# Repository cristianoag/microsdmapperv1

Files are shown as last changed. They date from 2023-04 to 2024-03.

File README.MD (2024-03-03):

# MSX microSD Mapper Wireless

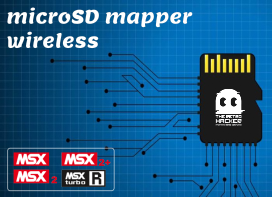
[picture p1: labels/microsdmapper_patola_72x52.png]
MicroSDMapper


The MSX microSD Mapper Wireless is a project aimed at building upon the success of Luciano Sturaro and Fabio Belavenuto's implementation of the well known MSX SD Mapper.

It features a single slot for microSD cards, a ESP8266 (ESP12E) micro-controller to offer wireless access, and simplified board design. 

With microSD cards becoming increasingly affordable and widely available, that seems to be a better option now. Additionally, the original SD Mapper v2 project had some confusion around the switches used to control the megaram/mapper, which were later changed in versions of the firmware to enable and disable the mapper on v2.

The ESP8266 enables network connectivity for the microSD card when it is inserted into the cartridge slot. Through a WebDAV server, it provides a convenient method for accessing and modifying the cartridge storage from any networked PC at any time, without requiring adapters, and eliminating the need for repeatedly removing and reinserting the memory card.

The cartridge also features a small OLED display to present the IP address acquired via DHCP and writes the information on a IP.CFG file on the root of the microSD card so you can create automation based on the address of the microSD Mapper. 

If you need detailed step by step instructions on how to build the cartridge, check the article written on the [The Retro Hacker](https://www.theretrohacker.com) website.

## Hardware Versions

* [microSDmapper v1.0](hardware/microsdmapper_v1.0/) - Initial test board with the basic configuration. (not working)
* [microSDmapper v1.1](hardware/microsdmapper_v1.1/) - Prototype board with the initial circuit, basic wiring for the ESP12E/8266 and a pin header to wire a display to show the MAC, and IP address acquired via DHCP. (not working without bodge wires)
* [microSDmapper v1.2](hardware/microsdmapper_v1.2/) - Prototype board with the validated circuit. Tested with the ESP12E/8266 and the access to the microSD card. (working)

## CPLD

The microSD Mapper is compatible with the standard VHDL code made by Fabio Belavenuto for the well known SD Mapper v2. It uses the Xilinx XC95144XL_TQ100 CPLD.

A copy of the source VHDL code, as well as the synthesized [sdmapper.jed](cpld/sdmapper.jed) file are available on this GitHub repository as a reference.

If you want to synthesize the code by yourself and/or program the CPLD you will need a Xilinx programmer and the Xilinx ISE Webpack.

## ESP8266/ESP12E Firmware

The ESP8266/ESP-12E microcontroller is used in the microSD mapper project to provide convenient access to the microSD card from a WebDav client, such as Windows Explorer. The microcontroller executes a program that implements a basic WebDav server, enabling access to the microSD content and allowing for wireless updates to its content.

Additionally, the microcontroller drives a small 128x32 OLED panel, displaying information on the status of the WebDav server and the IP address obtained by the Wireless interface.

The wireless network can be configured through a small website hosted on the root of the server. Upon the first boot, the ESP8266 activates a SoftAP that listens for HTTP connections made to 192.168.4.1. By accessing this website through a browser, the SSID and password for the wireless connection can be configured. Once saved, this configuration is stored on the ESP8266's EPROM and reused for subsequent connections. Modifications to the wireless configuration parameters can be made at any time by returning to the website.

When the webdav server starts, the code saves a file named IP.CFG on the root of the microSD card. If access to the OLED screen is not available, the IP.CFG file can be used to determine the IP address in use.

The code also monitors the CS signal and attaches itself to the "sdmapper bus". That is to avoid any conflicts with the MSX computer trying to save files at the same time you perform the same via the WebDav server.

## BIOS

The BIOS used on the microSD Mapper is a Nextor ROM that uses the driver created by Fabio Belavenuto and Fabio R. Schmidlin for the original SDMapper. I just made some changes on the assembly code to support the microSD mapper by detecting just one microSD card and also built the ROM using the the current/latest version (2.1.1) of the Nextor base. 

The modified code can be used to build the driver and the MKNEXROM tool can be used to built the Nextor ROM that needs to be flashed to the cartridge.

If you just want to flash a working version of the Nextor ROM to your cartridge, use the [FBL-UPD.COM](software/updater/FBL-UPD.COM) to load the [msdmap.rom](software/driver/msdmap.rom) executing the following command from your MSX-DOS or NEXTOR in a MSX with the microSD Mapper cartridge inserted:

```
FBL-UPD.COM msdmap.rom
```

After executing the command you will get a message that the BIOS was flashed to the cartridge.

If you want to build the driver from the source code, you will need to use [sjasmplus.exe](software/driver/sjasmplus.exe) to build the [driver.bin](software/driver/driver.bin) file and then use the [mknexrom.exe](software/driver/mknexrom.exe) tool to build the [msdmap.rom](software/driver/msdmap.rom) Nextor rom. 

You can do that by executing the commands below from the [driver](software/driver) folder:

```
sjasmplus.exe driver.asm

mknexrom.exe Nextor-2.1.1.base.dat msdmap.rom /d:driver.bin
```

## License 

Open Hardware

This work is licensed under a [Creative Commons Attribution-NonCommercial-ShareAlike 4.0 International License](http://creativecommons.org/licenses/by-nc-sa/4.0/).

* If you remix, transform, or build upon the material, you must distribute your contributions under the same license as the original.
* You may not use the material for commercial purposes.
* You must give appropriate credit, provide a link to the license, and indicate if changes were made. You may do so in any reasonable manner, but not in any way that suggests the licensor endorses you or your use.

**ATTENTION**

This project was made for the retro community and not for commercial purposes. So only retro hardware forums and individual people can build this project.

THE SALE OF ANY PART OF THIS PROJECT WITHOUT EXPRESS AUTHORIZATION IS PROHIBITED!

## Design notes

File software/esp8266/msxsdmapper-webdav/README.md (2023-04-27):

# WebDAV Server for the MSX MicroSD Mapper
This project based on the work done by ardyesp (https://github.com/ardyesp/ESPWebDAV) and synman (https://github.com/synman/ESPWebSvr/tree/sdFat-2.2.0)

The ESP8266/ESP-12E microcontroller is used in the microSD mapper project to provide convenient access to the microSD MSX card from a WebDav client, such as Windows Explorer. The microcontroller executes a program that implements a basic WebDav server, enabling access to the microSD content and allowing for wireless updates to its content.

Additionally, the microcontroller drives a small 128x32 OLED panel (optional), displaying information on the status of the WebDav server and the IP address obtained by the Wireless interface.

The wireless network can be configured through a small website hosted on the root of the server. Upon the first boot, the ESP8266 activates a SoftAP that listens for HTTP connections made to 192.168.4.1. By accessing this website through a browser, the SSID and password for the wireless connection can be configured. Once saved, this configuration is stored on the ESP8266's EPROM and reused for subsequent connections. Modifications to the wireless configuration parameters can be made at any time by returning to the website.

When the webdav server starts, the code saves a file named IP.CFG on the root of the microSD card. If access to the OLED screen is not available, the IP.CFG file can be used to determine the IP address in use.

The code also monitors the CS signal and attaches itself to the "sdmapper bus". That is to avoid any conflicts with the MSX computer trying to save files at the same time you perform the same via the WebDav server.

WiFi WebDAV server using ESP8266 SoC with changes to support the MSX MicroSD Mapper. It maintains the filesystem on an microSD card.

Supports the basic WebDav operations - *PROPFIND*, *GET*, *PUT*, *DELETE*, *MKCOL*, *MOVE* etc.

Once the WebDAV server is running on the ESP8266, a WebDAV client like Windows can access the filesystem on the SD card just like a cloud drive. The drive can also be mounted like a networked drive, and allows copying/pasting/deleting files on SD card remotely.

## Dependencies:
1. Adafruit GFX Library @ 1.11.5
2. Adafruit SSD1306 @ 2.5.7
3. SdFat @ 2.2.2

## Build And Deploy:

The card should be formatted for Fat16. The code also supports FAT32, but it works better with MSX if the card is formatted with FAT16.

This project is fully compatible with PlatformIO. Additionally, OTA is fully supported for subsequent flashes of the sketch over Wi-Fi.

Be sure to reset your adapter using its reset button after uploading a new firmware over USB.  The ESP8266 series modules will not properly reset / reboot
after a USB flash if not reset via their reset button first.  This limitation does not apply to OTA updates.

## Initial Setup
After booting the MSX with the microSD cartridge, wait approximately 60 seconds so the SoftAP gets activated. Once it indicates the WebDav server is running, connect to its Wi-Fi AP (MSXSDMAPPER).

Open up a browser and visit http://192.168.4.1

Fill in the hostname, ssid, and password fields with values that meet your needs and click the `Save` button.  Press the back button in your 
browser, refresh the page, and verify the values you entered meet your requirements.  Click the `Reboot` button to activate the changes.

After aproximiately 30 seconds, the WebDav server will be active and you can access it as described below, using the hostname you provided 
if your DHCP / DNS server support it.  Otherwise, the adapter will be available via its mDNS name `{hostname}`.`local`

You can revist the settings page at any time to reboot the adapter or update its settings.

## Usage:
To access the drive from Windows, type ```\\hostname_or_ip\DavWWWRoot``` at the Run prompt, or use Map Network Drive menu in Windows Explorer.

You can check the IP address on the IP.CFG file on the root of the microSDMapper filesystem or on the OLED Display (if available)

## Updating the ESP8266 firmware

You can use OTA to update the firmware. Load the project using PlatformIO and upload it using OTA.

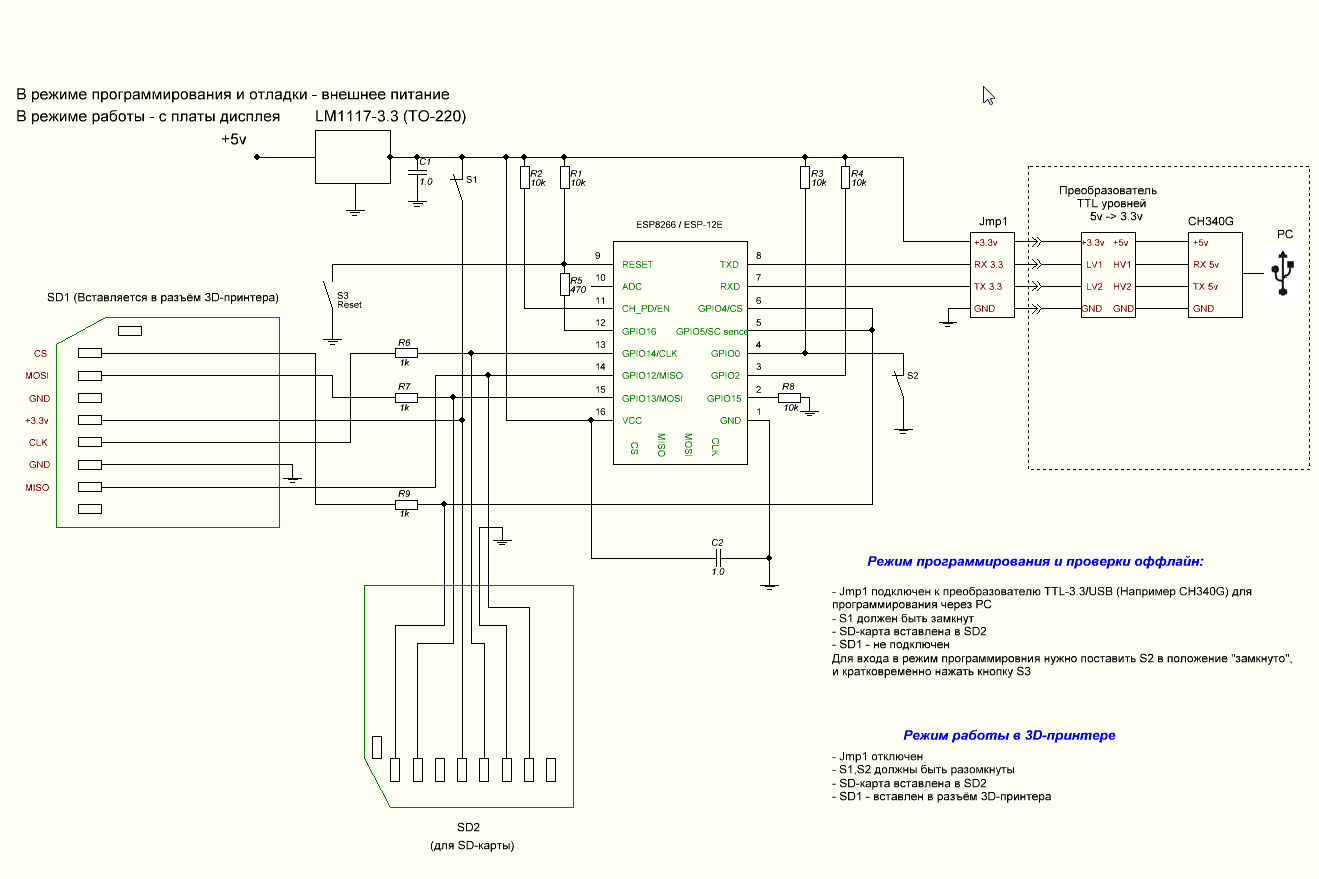
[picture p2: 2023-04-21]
docs/SDWIFI.png

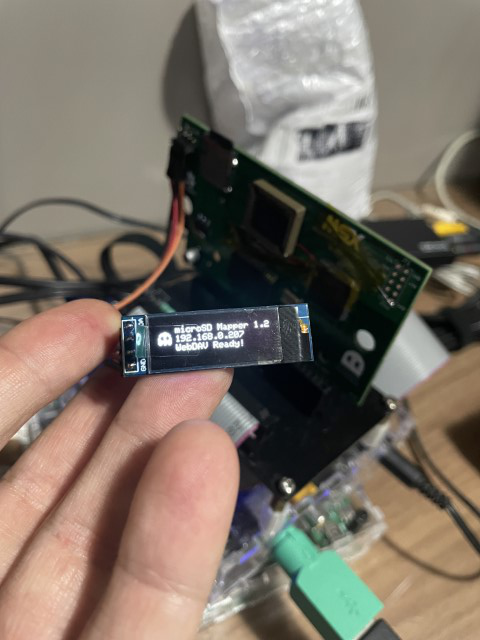
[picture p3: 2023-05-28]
images/20230528_191118884_iOS.jpg

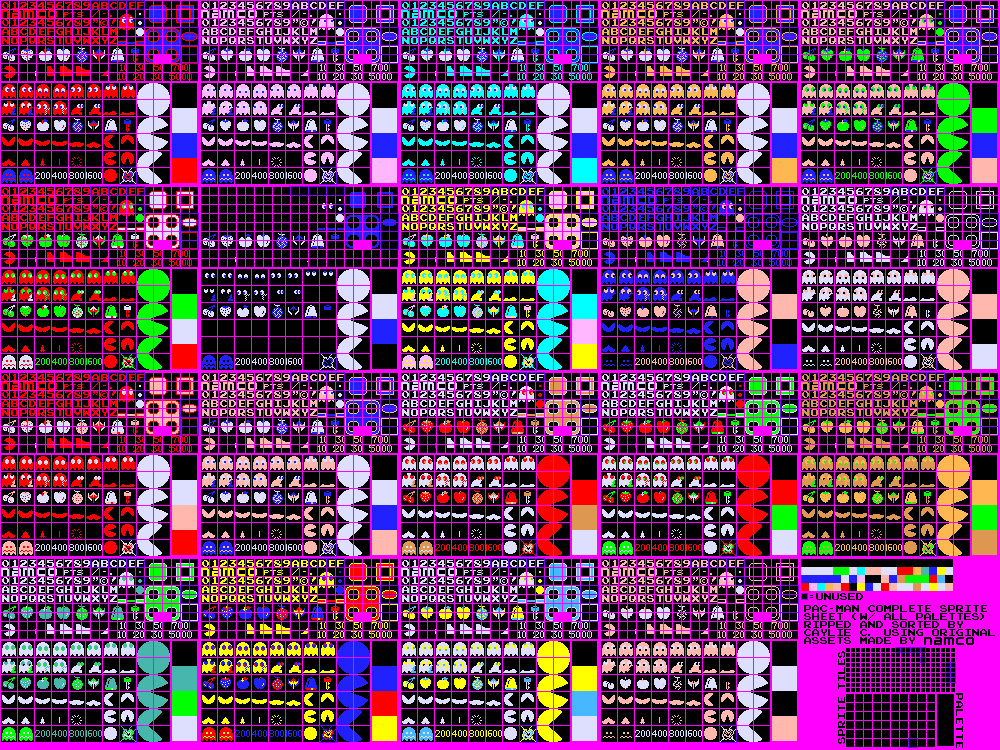
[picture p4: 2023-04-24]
images/Arcade - Pac-Man - All AssetsPalettes.png

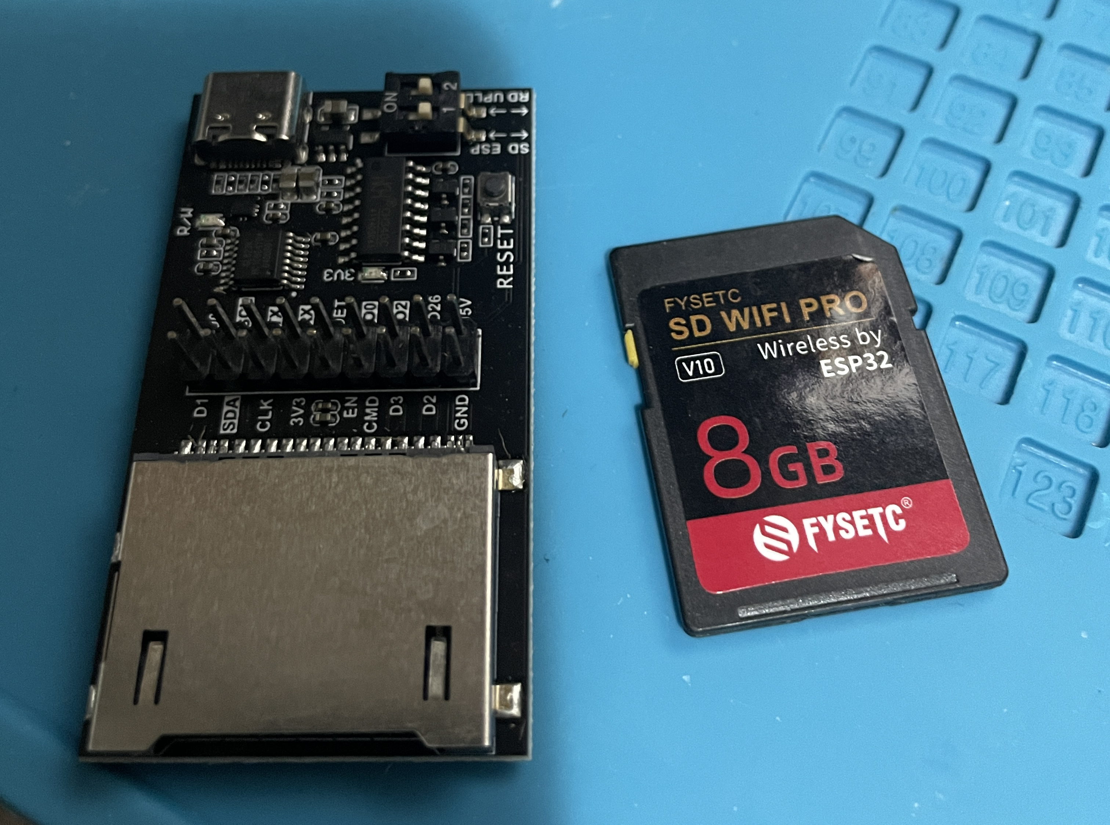
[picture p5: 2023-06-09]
images/20230609_212449081_iOS.jpg

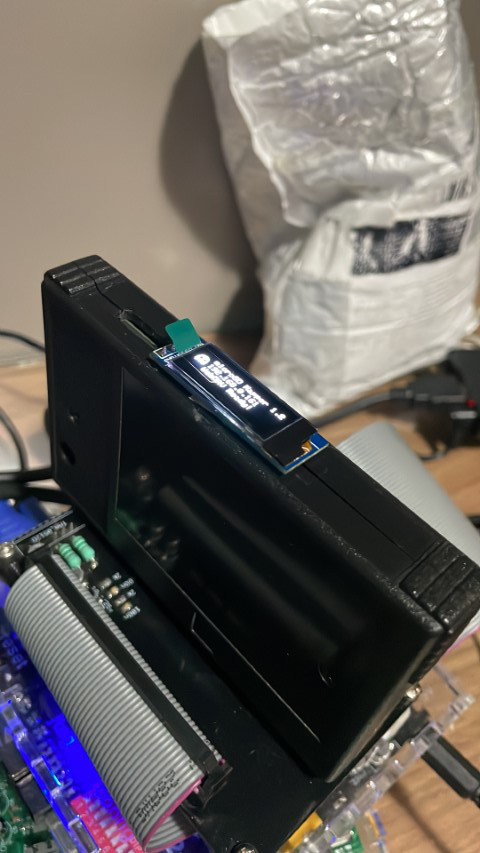
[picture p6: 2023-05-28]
images/20230528_223124077_iOS.jpg

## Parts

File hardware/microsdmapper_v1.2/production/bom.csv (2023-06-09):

Designator | Footprint | Quantity | Value | LCSC Part #
C1, C3, C4, C5, C6, C7, C8 | 0603 | 7 | 0.1uF
C2 | CP_Elec_5x4.5 | 1 | 100uF
D1 | LED_D3.0mm | 1 | LED
IC1 | PLCC-32_11.4x14.0mm_P1.27mm | 1 | M29F010
IC2 | SSOP-32_11.305x20.495mm_P1.27mm | 1 | HM628512
IC3 | VQFP-100_14x14mm_P0.5mm | 1 | XC95144XL_TQ100
J1 | PinHeader_2x03_P2.54mm_Vertical | 1 | Conn_02x03_Odd_Even
J2 | Conn_uSDcard | 1 | Micro_SD_Card_Det1
JT1 | PinHeader_2x05_P2.54mm_Vertical | 1 | JTAG1A
Q1 | SOT-23 | 1 | BC858
R1, R2, R3, R6 | 0603 | 4 | 1K
R10 | 0603 | 1 | 330
R4, R9 | 0603 | 2 | 4.7K
R5, R7, R8 | 0603 | 3 | 10K
U1 | XCVR_ESP8266-12E_ESP-12E | 1 | ESP8266-12E/ESP-12E
U2 | SOT-223-3_TabPin2 | 1 | LM1117MP-3.3
X1 | Crystal_SMD_7050-4Pin_7.0x5.0mm | 1 | 25 Mhz

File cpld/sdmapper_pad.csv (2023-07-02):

Release 8.1i - Fit P.20131013
Copyright(c) 1995-2003 Xilinx Inc. All rights reserved
7- 2-2023 10:55PM
NOTE: This file is designed to be imported into a spreadsheet program
such as Microsoft Excel for viewing | printing and sorting. The comma ' | '
character is used as the data field separator.
This file is also designed to support parsing.
Input file: sdmapper.ngd
output file: sdmapper_pad.csv
Part type: xc95144xl
Speed grade: -10
Package: tq100
Pinout by Pin Number:
----- | ----- | ----- | ----- | ----- | ----- | ----- | ----- | ----- | -----
Pin Number | Signal Name | Pin Usage | Pin Name | Direction | IO Standard | IO Bank Number | {blank} | Slew Rate | Termination | {blank} | Voltage | Constraint
P1 | sw_i<1> | I | I/O/GTS3 | INPUT
P2 | sw_i<0> | I | I/O/GTS4 | INPUT
P3 | TIE |  | I/O/GTS1
P4 | sd_miso_i | I | I/O/GTS2 | INPUT
P5 | VCC |  | VCCINT
P6 | sd_sclk_o | O | I/O | OUTPUT
P7 | sd_mosi_o | O | I/O | OUTPUT
P8 | sd_wp_i<1> | I | I/O | INPUT
P9 | sd_wp_i<0> | I | I/O | INPUT
P10 | sd_pres_n_i<0> | I | I/O | INPUT
P11 | TIE |  | I/O
P12 | TIE |  | I/O
P13 | TIE |  | I/O
P14 | TIE |  | I/O
P15 | data_bus_io<7> | I/O | I/O | BIDIR
P16 | data_bus_io<6> | I/O | I/O | BIDIR
P17 | data_bus_io<5> | I/O | I/O | BIDIR
P18 | data_bus_io<4> | I/O | I/O | BIDIR
P19 | data_bus_io<3> | I/O | I/O | BIDIR
P20 | data_bus_io<2> | I/O | I/O | BIDIR
P21 | GND |  | GND
P22 | clock_i | GCK | I/O/GCK1
P23 | data_bus_io<1> | I/O | I/O/GCK2 | BIDIR
P24 | data_bus_io<0> | I/O | I/O | BIDIR
P25 | addr_bus_i<5> | I | I/O | INPUT
P26 | VCC |  | VCCIO
P27 | addr_bus_i<4> | I | I/O/GCK3 | INPUT
P28 | addr_bus_i<3> | I | I/O | INPUT
P29 | addr_bus_i<2> | I | I/O | INPUT
P30 | addr_bus_i<1> | I | I/O | INPUT
P31 | GND |  | GND
P32 | addr_bus_i<0> | I | I/O | INPUT
P33 | addr_bus_i<14> | I | I/O | INPUT
P34 | addr_bus_i<13> | I | I/O | INPUT
P35 | addr_bus_i<12> | I | I/O | INPUT
P36 | wait_n_o | O | I/O | OUTPUT
P37 | addr_bus_i<8> | I | I/O | INPUT
P38 | VCC |  | VCCIO
P39 | TIE |  | I/O
P40 | TIE |  | I/O
P41 | addr_bus_i<7> | I | I/O | INPUT
P42 | addr_bus_i<6> | I | I/O | INPUT
P43 | addr_bus_i<11> | I | I/O | INPUT
P44 | GND |  | GND
P45 | TDI |  | TDI
P46 | TIE |  | I/O
P47 | TMS |  | TMS
P48 | TCK |  | TCK
P49 | busdir_n_o | O | I/O | OUTPUT
P50 | addr_bus_i<10> | I | I/O | INPUT
P51 | VCC |  | VCCIO
P52 | addr_bus_i<9> | I | I/O | INPUT
P53 | TIE |  | I/O
P54 | addr_bus_i<15> | I | I/O | INPUT
P55 | wr_n_i | I | I/O | INPUT
P56 | rd_n_i | I | I/O | INPUT
P57 | VCC |  | VCCINT
P58 | iorq_n_i | I | I/O | INPUT
P59 | m1_n_i | I | I/O | INPUT
P60 | TIE |  | I/O
P61 | TIE |  | I/O
P62 | GND |  | GND
P63 | TIE |  | I/O
P64 | TIE |  | I/O
P65 | ram_we_n_o | O | I/O | OUTPUT
P66 | sltsl_n_i | I | I/O | INPUT
P67 | rom_a_o<17> | O | I/O | OUTPUT
P68 | TIE |  | I/O
P69 | GND |  | GND
P70 | ram_a_o<13> | O | I/O | OUTPUT
P71 | TIE |  | I/O
P72 | TIE |  | I/O
P73 | TIE |  | I/O
P74 | TIE |  | I/O
P75 | GND |  | GND
P76 | rom_we_n_o | O | I/O | OUTPUT
P77 | rom_ce_n_o | O | I/O | OUTPUT
P78 | rom_a_o<14> | O | I/O | OUTPUT
P79 | rom_a_o<15> | O | I/O | OUTPUT
P80 | rom_a_o<16> | O | I/O | OUTPUT
P81 | ram_a_o<14> | O | I/O | OUTPUT
P82 | ram_a_o<15> | O | I/O | OUTPUT
P83 | TDO |  | TDO
P84 | GND |  | GND
P85 | ram_a_o<16> | O | I/O | OUTPUT
P86 | ram_a_o<17> | O | I/O | OUTPUT
P87 | ram_a_o<18> | O | I/O | OUTPUT
P88 | VCC |  | VCCIO
P89 | ram_cs_n_o | O | I/O | OUTPUT
P90 | TIE |  | I/O
P91 | TIE |  | I/O
P92 | TIE |  | I/O
P93 | sd_cs_n_o<0> | O | I/O | OUTPUT
P94 | sd_cs_n_o<1> | O | I/O | OUTPUT
P95 | TIE |  | I/O
P96 | sd_pres_n_i<1> | I | I/O | INPUT
P97 | TIE |  | I/O
P98 | VCC |  | VCCINT
P99 | reset_n_i | GSR/I | I/O/GSR
P100 | GND |  | GND
To preserve the pinout above for future design iterations in
Project Navigator simply execute the (Lock Pins) process
located under the (Implement Design) process in a toolbox named
(Optional Implementation Tools) or invoke PIN2UCF from the
command line. The location constraints will be written into your
specified UCF file

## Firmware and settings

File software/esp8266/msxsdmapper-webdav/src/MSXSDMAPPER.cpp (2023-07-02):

// Using the WebDAV server with MSX microSD mapper
// Author: Cristiano Goncalves
// Based on work of synman available at https://github.com/synman/ESPWebSvr/tree/sdFat-2.2.0

#include <Arduino.h> //conversion to platformio
#include <ArduinoOTA.h> //using over the air to update the firmware

#include <ESP8266WiFi.h>
#include <ESP8266mDNS.h>
#include <EEPROM.h>
#include <user_interface.h>
#include <SPI.h>
#include <SdFat.h>

#include <Wire.h>
#include <Adafruit_GFX.h>
#include <Adafruit_SSD1306.h>

#include "ESPWebDAV.h"

#define OLED_DISPLAY 1 //set to 1 if you have a 128x32 oled display connected to the board

#define BM_WDT_SOFTWARE 0
#define BM_WDT_HARDWARE 1
#define BM_ESP_RESTART 2
#define BM_ESP_RESET 3

#define BOOT_MODE BM_WDT_SOFTWARE
#define HOSTNAME    "MSXSDMAPPER"

// LED is connected to GPIO2 on this board
#define INIT_LED			{pinMode(2, OUTPUT);}

#define SD_CS		4
#define MISO		12
#define MOSI		13
#define SCLK		14
#define CS_SENSE	5

//only if the board supports OLED_DISPLAY (need to be ESP12E to have enough pins)
#if OLED_DISPLAY == 1
// OLED_DISPLAY pins
#define DSP_SCA 	9
#define DSP_SCK 	10
// OLED_DISPLAY control
#define SCREEN_WIDTH 128 // OLED display width, in pixels
#define SCREEN_HEIGHT 32 // OLED display height, in pixels
#define OLED_RESET -1 // Reset pin not used
#endif

#define SERVER_PORT		80
#define SPI_BLOCKOUT_PERIOD	20000UL

uint32 sys_time = system_get_time();
CONFIG_TYPE config;

const char *hostname 	= HOSTNAME;
const char *ssid 		= "";
const char *pwd 		= "";
WiFiMode_t wifimode     = WIFI_AP;

#if OLED_DISPLAY == 1
Adafruit_SSD1306 display(SCREEN_WIDTH, SCREEN_HEIGHT, &Wire, OLED_RESET);
#endif

ESPWebDAV dav;
String statusMessage;
bool initFailed = false;

volatile unsigned long spiBlockoutTime = 0;
bool weHaveBus = false;

#if OLED_DISPLAY == 1
//ghost bitmap
const unsigned char PACMAN_GHOST [] PROGMEM = {
    0b00000000, 0b00000000, // Row 1
    0b00000011, 0b11000000, // Row 2
    0b00001111, 0b11110000, // Row 3
    0b00011111, 0b11111000, // Row 4
    0b00111111, 0b11111100, // Row 5
    0b00110011, 0b11001100, // Row 6
    0b00100001, 0b10000100, // Row 7
    0b01100001, 0b10000110, // Row 8
    0b01100001, 0b10000110, // Row 9
    0b01110011, 0b11001110, // Row 10
    0b01111111, 0b11111110, // Row 11
    0b01111111, 0b11111110, // Row 12
    0b01111111, 0b11111110, // Row 13
    0b01111011, 0b11011110, // Row 14
    0b00110001, 0b10001100, // Row 15
    0b00000000, 0b00000000  // Row 16
};
#endif

// ------------------------
void takeBusControl()	{
// ------------------------
	weHaveBus = true;
	LED_ON;
	pinMode(MISO, SPECIAL);	
	pinMode(MOSI, SPECIAL);	
	pinMode(SCLK, SPECIAL);	
	pinMode(SD_CS, OUTPUT);
}

// ------------------------
void relenquishBusControl()	{
// ------------------------
	pinMode(MISO, INPUT);	
	pinMode(MOSI, INPUT);	
	pinMode(SCLK, INPUT);	
	pinMode(SD_CS, INPUT);
	LED_OFF;
	weHaveBus = false;
}

// ------------------------
void blink()	{
// ------------------------
	LED_ON; 
	delay(100); 
	LED_OFF; 
	delay(400);
}

// ------------------------
void errorBlink()	{
// ------------------------
	for(int i = 0; i < 100; i++)	{
		LED_ON; 
		delay(50); 
		LED_OFF; 
		delay(50);
	}
}

#if OLED_DISPLAY == 1
//display messages on the 128x32 oled screen
void Display(String msg1, String msg2)
{
    display.clearDisplay();
    //show the logo on the OLED_DISPLAY on the left side, vertical centralized
    int16_t y = (SCREEN_HEIGHT - 14) / 2; // calculate the vertical position
    display.drawBitmap(0, y, PACMAN_GHOST, 16, 16, WHITE);
    //set cursor
    display.setTextSize(1);
    display.setTextColor(WHITE);
    //display first line
    display.setCursor(20, 4);
    display.print("microSD Mapper 1.2");
    display.setCursor(20, 14);
    display.print(msg1);
    display.setCursor(20, 24);
    display.print(msg2);
    // Update the display
    display.display();
}
#endif

// ------------------------
void setup() {
  	DBG_INIT(115200);
	DBG_PRINTLN("\nMSXSDMAPPER setup");

#if OLED_DISPLAY == 1
	Wire.begin(DSP_SCA, DSP_SCK); // SDA, SCK
	display.begin(SSD1306_SWITCHCAPVCC, 0x3C);
    display.clearDisplay();
    display.display();
#endif

	EEPROM.begin(EEPROM_SIZE);
	uint8_t *p = (uint8_t*)(&config);
	for (uint8 i = 0; i < sizeof(config); i++)
	{
		*(p + i) = EEPROM.read(i);
	}
	EEPROM.commit();

	if (config.hostname_flag == 9) {
		DBG_PRINT("config host="); DBG_PRINTLN(config.hostname);
		hostname = config.hostname;
	} 
	if (config.ssid_flag == 9) {
		DBG_PRINT("config ssid="); DBG_PRINTLN(config.ssid);
		ssid = config.ssid;
		wifimode = WIFI_STA;
	} 
	if (config.pwd_flag == 9) {
		DBG_PRINT("config pwd="); DBG_PRINTLN(config.pwd);
		pwd = config.pwd;
	} 

	INIT_LED;
	blink();
	
	WiFi.hostname(hostname);
	WiFi.mode(wifimode);
	WiFi.setAutoConnect(false);
	WiFi.setPhyMode(WIFI_PHY_MODE_11N);

	if (wifimode != WIFI_AP) {
		WiFi.begin(ssid, pwd);
		// Wait for connection
		DBG_PRINT("Connecting to WiFi .");
#if OLED_DISPLAY == 1
		Display("Connecting to WiFi",ssid);
#endif
		for (uint8 x = 0 ; x < 60 && WiFi.status() != WL_CONNECTED; x++) {
			blink();
			DBG_PRINT(".");
		}
		
	}
	
	if (WiFi.status() != WL_CONNECTED) {
		wifimode = WIFI_AP;
		WiFi.softAP(HOSTNAME);
		DBG_PRINTLN("\nSoftAP [MSXSDMAPPER / 192.168.4.1] started");
	}

	if (!MDNS.begin(hostname)) { 
		DBG_PRINTLN("\nError setting up mDNS responder!");
	} else {
		DBG_PRINTLN("\nmDNS successfully activated");
		MDNS.update();
	}
  
   	ArduinoOTA.begin();

	DBG_PRINTLN("");
  	DBG_PRINT("    Hostname: "); DBG_PRINTLN(hostname);
	DBG_PRINT("Connected to: "); DBG_PRINTLN(ssid);
	DBG_PRINT("  IP address: "); DBG_PRINTLN(WiFi.localIP());
	DBG_PRINT("        RSSI: "); DBG_PRINTLN(WiFi.RSSI());
	DBG_PRINT("        Mode: "); DBG_PRINTLN(WiFi.getPhyMode());

	DBG_PRINT("\nAttaching to the SD bus .");

	// Detect when other master uses SPI bus
	pinMode(CS_SENSE, INPUT);
	attachInterrupt(CS_SENSE, []() {
		if(!weHaveBus)
			spiBlockoutTime = millis() + SPI_BLOCKOUT_PERIOD;
	}, FALLING);

	// sleep for 30 seconds
	// we don't want to be touching the SD card 
	// if we are connected to a printer and its
	// bootloader is trying to install a firmware bin
	for (uint8 x = 0 ; x < 30 ; x++) {
		DBG_PRINT(".");
		blink();
		delay(500);
#if OLED_DISPLAY == 1
		Display(WiFi.localIP().toString(),"Starting...");
#endif
	}

	for (uint8 x = 0 ; x * 1000 < SPI_BLOCKOUT_PERIOD ; x = x + 1) {
		// wait for other master to assert SPI bus first
		DBG_PRINT(".");
		blink();
		delay(500);
	}
  
	// ----- SD Card and Server -------
	// Check to see if other master is using the SPI bus
	while(millis() < spiBlockoutTime) {
		DBG_PRINT(".");
		blink();
	}
	
	takeBusControl();
	
	// start the SD DAV server
	if(!dav.init(SD_CS, SERVER_PORT)) {
		statusMessage = "Failed to initialize SD Card";
		DBG_PRINT("\nERROR: "); DBG_PRINTLN(statusMessage);
#if OLED_DISPLAY == 1
		Display("ERROR",statusMessage);
#endif
		// indicate error on LED
		errorBlink();
		initFailed = true;
	} else {
		blink();
		DBG_PRINTLN("\nWebDAV server started");
#if OLED_DISPLAY == 1
		if (config.ssid_flag == 9) {
			Display(WiFi.localIP().toString(),"WebDAV Ready!");
		}
		else
		{
			Display(WiFi.localIP().toString(),"SoftAP Active");
		}
#endif
  	}

	relenquishBusControl();
}

// ------------------------
void loop() {
// ------------------------
	MDNS.update();
	ArduinoOTA.handle();

	if(millis() < spiBlockoutTime)
		blink();

	// do it only if there is a need to read FS
	if(dav.isClientWaiting())	{
		if(initFailed)
			return dav.rejectClient(statusMessage);
		
		// has other master been using the bus in last few seconds
		if(millis() < spiBlockoutTime)
			return dav.rejectClient("MSX is reading from SD card. Wait a few seconds and refresh.");
		
		// a client is waiting and FS is ready and other SPI master is not using the bus
		takeBusControl();
		dav.handleClient();
		relenquishBusControl();
	}

	// reboot every 6 hours
	if (sys_time / 1000 / 1000 + 21600 <= system_get_time() / 1000 / 1000)  {
		DBG_PRINT("Requesting scheduled reboot ref="); DBG_PRINT(sys_time / 1000 / 1000 + 21600); DBG_PRINT(" cur="); DBG_PRINTLN(system_get_time() / 1000 / 1000);
		reboot = true;    
	}

	if (reboot || initFailed) {
		initFailed = false;
		reboot = false;
		DBG_PRINTLN("REBOOTING");
		errorBlink();
		#if BOOT_MODE == BM_ESP_RESTART
		Serial.println("\n\nRebooting with ESP.restart()");
		ESP.restart();
		#elif BOOT_MODE == BM_ESP_RESET
		Serial.println("\n\nRebooting with ESP.reset()");
		ESP.reset();
		#else 
		#if BOOT_MODE == BM_WDT_HARDWARE      
			Serial.println("\n\nRebooting with hardware watchdog timeout reset");
			ESP.wdtDisable();
		#else
			Serial.println("\n\nRebooting with sofware watchdog timeout reset");
		#endif  
		while (1) {}  // timeout!
		#endif 
	}
}

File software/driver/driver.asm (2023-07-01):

; Projeto MSX SD-Mapper

; Copyright (c) 2014 Fabio Belavenuto
; Copyright (c) 2017, 2018 Fabio R. Schmidlin 
; Copyright (c) 2023 Cristiano Goncalves (Adapting the code to support the microSD Mapper Wireless)

; This documentation describes Open Hardware and is licensed under the CERN OHL v. 1.1.
; You may redistribute and modify this documentation under the terms of the
; CERN OHL v.1.1. (http://ohwr.org/cernohl). This documentation is distributed
; WITHOUT ANY EXPRESS OR IMPLIED WARRANTY, INCLUDING OF MERCHANTABILITY,
; SATISFACTORY QUALITY AND FITNESS FOR A PARTICULAR PURPOSE.
; Please see the CERN OHL v.1.1 for applicable conditions

; Technical info:
; 7B00h~7EFFh	: SPI data transfer window (read/write)
; 7FF0h		: Interface status and card select register (read/write)
;	<read>
;	If no SD card is selected:
;	    b7-b2 : always 0
;	    b1 : SW1 status (Driver selection)
;	    b0 : SW0 status. 0=RAM disabled, 1=RAM enabled
;	If any SD card is selected:
;	    b7-b3 : always 0
;	    b2 : 1=Write protecton enabled for SD card-slot selected
;	    b1 : 0=SD card present in the selected card-slot
;	    b0 : 1=SD Card on slot selected changed since last read
;	<write>
;	    b0 : SD card slot-0 chip-select (1=selected)
;	    b1 : SD card slot-1 chip-select (1=selected)

; 7FF1h		: 8-bit timer (97.65625 KHz frequency, 10.24uS resolution) (read/write)
; When a value is written, the timer will decrease it until it reaches zero
;
;
; A Special thanks goes to Elm-chan, for publishing the documentation we used to
; create this driver. http://elm-chan.org/docs/mmc/mmc_e.html

	output	"driver.bin"

;-----------------------------------------------------------------------------
;
; Driver configuration constants
;

CMDTIMEOUT	equ	2	; Command accepted timeout	: 2*2.6nS
READYTIMEOUT	equ	385	; Card ready timeout		: 10 second
DETTIMEOUT	equ	385	; Detection timeout		: 385*2.6nS = 1 second
 DEFINE TURBOINIT	; Execute DRV_INIT with the turbo enabled 
 DEFINE DSKEMU		; Include a built-in floppy disk emulator
; DEFINE PARALLELCARD	; Allows parallel card processing. Seems to require
			; independent communication lines for each card
; DEFINE HASMEGARAM	; Driver for an SD-Mapper with MegaRAM
; DEFINE DEBUG1		; Enable level-1 debugging (Only status queries)
; DEFINE DEBUG2		; Enable level-2 debugging (RW calls)
; DEFINE DEBUG3		; Enable level-3 debugging (requires level-1). Also logs invalid DEVs and LUN numbers


;Driver type:
;   0 for drive-based
;   1 for device-based

DRV_TYPE	equ	1

;Hot-plug devices support (device-based drivers only):
;   0 for no hot-plug support
;   1 for hot-plug support

DRV_HOTPLUG	equ	1


;Driver version

VER_MAIN	equ	1
VER_SEC		equ	1
VER_REV		equ	0

;-----------------------------------------------------------------------------
; SPI addresses. Check the Technical info above for the bit contents

SPIDATA		= $7B00		; read/write
SPICTRL		= $7FF0		; write
SPISTATUS	= $7FF0		; read
TIMERREG	= $7FF1		; read/write

; Interface status flags
IF_RAM		= 0		; 1=Interface RAM is enabled
IF_DRVER	= 1		; RAM mode: 0=MegaRAM, 1=MemoryMapper
IF_M_RAM	= (1 shl IF_RAM)		; bitmask for IF_RAM
IF_M_DRVER	= (1 shl IF_DRVER)		; bitmask for IF_DRVER

; card slot status flags
SD_DSKCHG	= 0		; SD card changed since last status check
SD_PRESENT	= 1		; SD card present
SD_WRTPROT	= 2		; SD card is write protected
SD_M_DSKCHG	= (1 shl SD_DSKCHG)		; bitmask for SD_DSKCHG
SD_M_PRESENT	= (1 shl SD_PRESENT)		; bitmask for SD_PRESENT
SD_M_WRTPROT	= (1 shl SD_WRTPROT)		; bitmask for SD_WRTPROT

; SPI commands: 
CMD0	= 0  | $40
CMD1	= 1  | $40
CMD8	= 8  | $40
CMD9	= 9  | $40
CMD10	= 10 | $40
CMD12	= 12 | $40
CMD13	= 13 | $40
CMD16	= 16 | $40
CMD17	= 17 | $40
CMD18	= 18 | $40
CMD24	= 24 | $40
CMD25	= 25 | $40
CMD55	= 55 | $40
CMD58	= 58 | $40
ACMD23	= 23 | $40
ACMD41	= 41 | $40

; SD card errors
R1ERR:
.IDLE		= 1	; In idle state
.ERARST		= 2	; Erase reset
.ILLGCMD	= 3	; Illegal command
.CRCERR		= 4	; Communication CRC error
.ERAERR		= 5	; Erase sequence error
.ADDRERR	= 6	; Address error
.PARMERR	= 7	; Parameter error
.M_IDLE		= (1 shl .IDLE)
.M_ERARST	= (1 shl .ERARST)
.M_ILLGCMD	= (1 shl .ILLGCMD)
.M_CRCERR	= (1 shl .CRCERR)
.M_ERAERR	= (1 shl .ERAERR)
.M_ADDRERR	= (1 shl .ADDRERR)
.M_PARMERR	= (1 shl .PARMERR)

; Work area stuctures 
 STRUCT WRKAREA
TRLDIR		dw	; Pointer to the R800 data transfer helper
NUMSD		db 	; Currently selected card: 1 or 2 
CARDFLAGS	db 	; Flags that indicate card-change or card error 
			; b0: card1 error
			; b1: card2 error
			; b2: card1 LUN changed flag
			; b3: card2 LUN changed flag
			; b4: card1 DEV changed flag
			; b5: card2 DEV changed flag
			; b6: card1 version
			; b7: card2 version
NUMBLOCKS	db 	; Number of blocks in multi-block operations 
TEMP		db	; Buffer for temporary data 
DSKEMU.DSKDEV	db	; Floppy emulation: b0~b2=DEV, b3~b7=Disk number 
;DSKEMU.VDPDR	db	; VDP.DR cached value
DSKEMU.VDPDW	db	; VDP.DW cached value
 ENDS

; WRKAREA.CARDFLAGS shift amount and direction
WCF_N_ERROR	= 0	; SD card error
WCF_L_LUNCHG	= 2	; LUN has changed software flag
WCF_L_DEVCHG	= 4	; Device has changed software flag
WCF_R_CRDVER	= 2	; Current card version

 STRUCT CID
MID		db	; Manufacturer ID
OID		ds 2	; OEM ID
PNM		ds 5	; Product Name
PRV		db
PSN		ds 4	; Product Serial Number
RSVMDT		dw	; Reserved, Manufacturing date
CRC		db	; b7=1, b6~b0 = CRC7 checksum
 ENDS

 STRUCT WTMPDATA
BUFFER		ds 512	; Buffer for the IDENTIFY info
SECTNUM		dd	; Pointer to the text "Master:" or "Slave:"
 ENDS



;-----------------------------------------------------------------------------
;
; Standard BIOS and work area entries
CALSLT	= $001C		; Call routine in any slot
CALLF	= $0030		; Call routine in any slot
INITXT	= $006C		; Inicializa SCREEN0
CHSNS	= $009C		; Sense keyboard buffer for character
CHGET	= $009F		; Get character from keyboard buffer
CHPUT	= $00A2		; A=char
BEEP	= $00C0		; Does a beep
CLS	= $00C3		; Chamar com A=0
ERAFNK	= $00CC		; Erase function key display
SNSMAT	= $0141		; Read row of keyboard matrix
KILBUF	= $0156		; Clear keyboard buffer
EXTROM	= $015F
CHGCPU	= $0180		; Change the turbo mode
GETCPU	= $0183		; Get the turbo mode

; subROM functions
SDFSCR	= $0185
REDCLK	= $01F5


; System variables
VDP.DR	= $0006
VDP.DW	= $0007
MSXVER	= $002D
LINL40	= $F3AE		; Width
LINLEN	= $F3B0
TEMP3	= $F69D
INTFLG	= $FC9B
SCRMOD	= $FCAF
EXPTBL	= $FCC1
RG15SA	= $FFEE		; VDP Register 15 Save copy.



;-----------------------------------------------------------------------------


	org		$4000

	ds		256, $FF		; 256 dummy bytes

DRV_START:

;-----------------------------------------------------------------------------
;
; Miscellaneous constants
;

;This is a 2 byte buffer to store the address of code to be executed.
;It is used by some of the kernel page 0 routines.

CODE_ADD:	equ	$F1D0


;-----------------------------------------------------------------------------
;
; Error codes for DEV_RW
;
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

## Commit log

2023-03-22 gerbers and interactive bom
    [bom.csv, designators.csv, positions.csv]
2023-04-21 v1.1 with wifi/esp8266
    [bom.csv, designators.csv, microsdmapper.kicad_sch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]
2023-05-28 v1.2 and a few code changes
    [bom.csv, designators.csv, microsdmapper.kicad_sch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]
2023-06-09 v1.2 and images
    [bom.csv, designators.csv, microsdmapper.kicad_sch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]
2023-07-02 Fixes to the ESP8266 firmware
    [sdmapper_pad.csv]
2023-07-09 Fix led and new gerbers
    [designators.csv, microsdmapper.kicad_sch]
2023-07-09 New BOM after led fix
2023-07-09 adding silk logos
    [designators.csv]
2023-08-27 Adjustments on the PCB for prototype build
    [designators.csv, microsdmapper.kicad_sch]
